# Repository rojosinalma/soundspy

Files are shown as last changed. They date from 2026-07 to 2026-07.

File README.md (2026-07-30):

<p align="center">
  soundspy logo
</p>

<h1 align="center">soundspy</h1>
<p align="center">Real-time multi-node sound monitoring system for ESP32</p>

---

ESP32 nodes with I2S microphones sample audio, perform 6-band frequency analysis, and publish to a web dashboard via MQTT. Designed to monitor when audio production might be disturbing neighbors through shared walls.

## Requirements

**Hardware (per node)**
- ESP32 development board
- ICS-43434 or INMP441 I2S MEMS microphone

**Software**
- Docker + Docker Compose
- Arduino CLI (for firmware builds) — or Arduino IDE

## Setup

**1. Configure environment**
```bash
cp .env.example .env
# Edit .env with your WiFi credentials and server IP
```

**2. Start services**
```bash
docker compose up -d
```
Dashboard: `http://<server-ip>:8091`

**3. Build and flash firmware**
```bash
./scripts/build_firmware.sh
# Initial flash via USB:
arduino-cli upload -p /dev/ttyUSB0 --fqbn esp32:esp32:esp32 \
  --input-file builds/soundspy_latest.bin
```
Subsequent updates can be done via OTA from the dashboard.

**Hardware wiring (I2S mic → ESP32)**

| Mic Pin | ESP32 GPIO |
|---|---|
| VDD | 3.3V |
| GND | GND |
| SD | GPIO32 |
| WS | GPIO25 |
| SCK | GPIO33 |
| L/R | GND |

## Development

**Project structure**
```
node_firmware/node_firmware.ino   — ESP32 firmware
dashboard/dashboard.py            — Flask + SocketIO backend
dashboard/templates/dashboard.html — Web UI
dashboard/threshold_monitor.py    — Alert service
scripts/build_firmware.sh         — Build script
scripts/deploy_ota.sh             — OTA deploy script
```

**OTA deploy to a node**
```bash
./scripts/deploy_ota.sh <chip_id>
# chip_id visible in dashboard or serial output on boot
```

**Useful commands**
```bash
docker logs -f soundspy_dashboard   # Dashboard logs
docker logs -f soundspy_monitor     # Alert service logs
```

## Documentation

Full documentation is available on the [project wiki](https://github.com/rojosinalma/soundspy/wiki):

- [Architecture](https://github.com/rojosinalma/soundspy/wiki/Architecture)
- [Hardware Wiring](https://github.com/rojosinalma/soundspy/wiki/Hardware-Wiring)
- [Firmware Setup](https://github.com/rojosinalma/soundspy/wiki/Firmware-Setup)
- [Dashboard](https://github.com/rojosinalma/soundspy/wiki/Dashboard)
- [Adding Nodes](https://github.com/rojosinalma/soundspy/wiki/Adding-Nodes)
- [Troubleshooting](https://github.com/rojosinalma/soundspy/wiki/Troubleshooting)

## Screenshot

<p align="center">
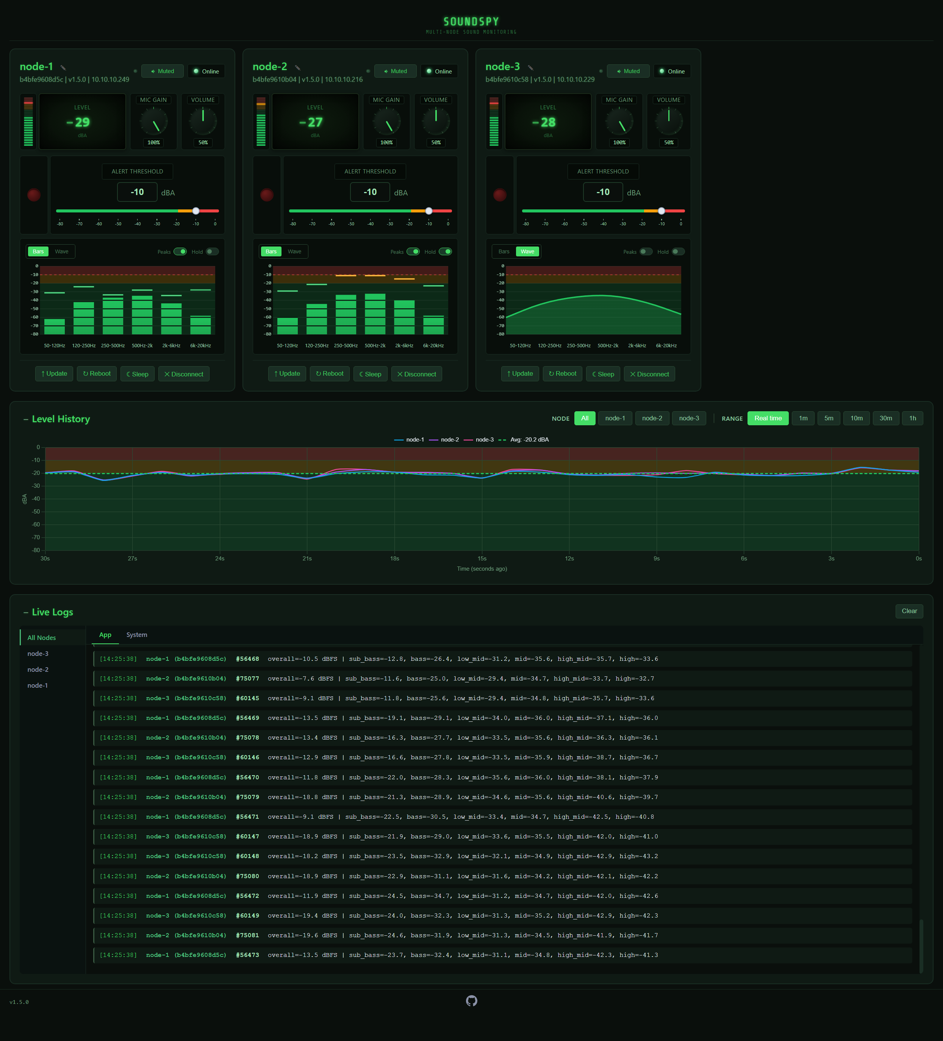
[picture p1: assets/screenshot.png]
soundspy dashboard
  
</p>

## License

[AGPL-3.0](LICENSE)

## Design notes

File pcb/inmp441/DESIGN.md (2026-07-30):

# INMP441 Mic Module

Circular breakout board with INMP441 MEMS I2S microphone.

## Module Specs

- **Dimensions:** 14mm diameter, 3mm height
- **Interface:** I2S
- **Header:** 2x3, 2.54mm column pitch, 7.62mm row separation
- **Drill:** 0.762mm, pad diameter 1.524mm
- **Sound port hole:** 3mm center drill

## Pin Layout

```
  GND   VDD   SD
   ●     ●     ●
  ( microphone  )
   ●     ●     ●
  LR    WS    SCK
```

| Pin | Signal | ESP32 GPIO |
|-----|---|---|
| VDD | 3.3V | 3.3V |
| GND | Ground | GND |
| SD  | I2S Data out | GPIO32 |
| WS  | I2S Word Select | GPIO25 |
| SCK | I2S Clock | GPIO33 |
| LR  | Channel select | GND (left channel) |

## Reference

- KiCad schematic symbol and footprint (legacy KiCad 4/5 format):
  https://github.com/barafael/inmp441-breakout-kicad

## Carrier Board Integration

The INMP441 module mounts on the `soundspy-node` carrier board (`pcb/soundspy-node.kicad_pcb`) via the 2x3 pin header. The carrier board has:

- A 3mm through-hole aligned with the mic's sound port
- 100nF decoupling cap (C1) on the 3V3 line near the connector
- Board outline: 30×68mm with USB-C notch at the bottom

## Notes

- LR pin must be tied to GND for left channel selection — connected to GND net on the carrier
- Route LR to GND during PCB layout in KiCad
- The carrier PCB is unrouted — open `soundspy-node.kicad_pcb` in KiCad and use the ratsnest to complete routing

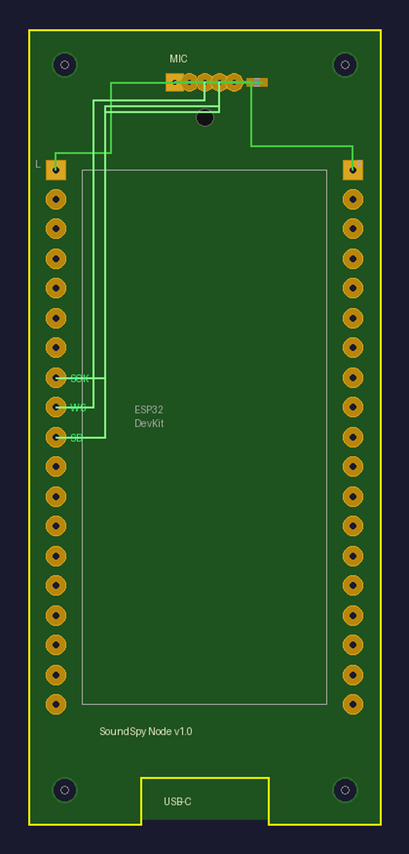
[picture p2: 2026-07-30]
pcb/inmp441/soundspy-node-preview.png

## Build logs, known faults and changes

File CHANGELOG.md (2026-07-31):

# Changelog

All notable changes to the soundspy project will be documented in this file.

The format is based on [Keep a Changelog](https://keepachangelog.com/en/1.0.0/),
and this project adheres to [Semantic Versioning](https://semver.org/spec/v2.0.0.html).

## Versioning Policy

- **MAJOR.MINOR.PATCH** (e.g., 0.8.3)
- **PATCH**: Bug fixes, optimization, logging changes (0.8.2 → 0.8.3)
- **MINOR**: New features, new capabilities (0.8.x → 0.9.0)
- **MAJOR**: Breaking changes, protocol changes, incompatible with dashboard (0.x.x → 1.0.0)

## [Unreleased]

## [1.6.0] - 2026-07-31

### Added
- EQ spectrum peak markers: always visible, fade after 2s by default
- Peaks toggle: hide/show peak markers per node
- Peak Hold toggle: keep markers indefinitely until exceeded again; enabling hold auto-enables peaks, disabling peaks auto-disables hold
- Per-node threshold persistence across page reloads (`data/node_thresholds.json`)
- System logs persist across reload: server keeps last 200, replays to new clients on connect
- Node name shown alongside chip ID in all log entries

### Changed
- Default mic gain raised to 100% (10x) for accurate level reporting
- Node chip ID now uses full 6-byte MAC (was lower 4 bytes) — fixes duplicate IDs on boards from same batch
- Threshold stored exactly as set by user — removed dBFS/dBA recalculation that caused drift on reload
- Offline status LED is now static red with glow (was dim green)
- Node history chart colors changed to blues/purples/pinks (avoids conflict with green/yellow/red zone colors)

### Fixed
- Node cards no longer flash: staleness check now uses browser clock (`Date.now()`) instead of server timestamp — eliminates clock-skew false positives
- Canvas no longer resets every frame: DPR dimensions rounded to integer, preventing always-true size mismatch
- DOM writes guarded against no-op updates; sensor data batched via `requestAnimationFrame`
- App log no longer causes layout thrashing at 50Hz — throttled to 1s renders

## [1.5.0] - 2026-07-31

### Changed
- Node chip ID now uses full 6-byte MAC (was lower 4 bytes) — fixes duplicate IDs on boards from same batch

### Fixed
- Release workflow no longer attempts to package PCB files (handled separately by `pcb-release.yml`)

## [1.4.9] - 2026-07-30

### Added
- Project wiki with full documentation (Architecture, Hardware Wiring, Firmware Setup, Dashboard, Adding Nodes, Troubleshooting)
- Wiki links in README
- AGPL-3.0 license
- VERSION file as single source of truth; bump_version.sh script to update all version strings at once
- GitHub Actions workflow to auto-tag and release when VERSION increases

## [1.4.8] - 2026-07-30

### Fixed
- Wave mode: fill and stroke gradients use hard stops at zone boundaries — no more yellow bleeding below threshold

## [1.4.7] - 2026-07-30

### Added
- Alert LED: red dome indicator next to threshold box, lights up instantly on threshold breach using raw level (not EMA-smoothed)

### Changed
- Audio indicator and online dot styled as LEDs: radial gradient highlight, glow when active, dark recessed dome when off
- Blink animation dimmer (35% opacity) for more visible pulse
- Status pill gap increased to 8px
- Node card no longer flashes border on alert — LED is the sole indicator
- Band frequency labels aligned to 6-column grid matching bar positions
- Spectrum canvas taller (160px), Y-axis narrower (30px)
- eq-container: dark bg + border matching control boxes

## [1.4.6] - 2026-07-30

### Added
- Dashboard version in footer (bottom-left, monospace, served from DASHBOARD_VERSION constant)
- watchdog hot-reload: template and Python changes now apply without container restart

### Changed
- Spectrum canvas renders at device pixel ratio — fixes blurry Y-axis text on HiDPI displays
- Spectrum canvas taller (160px), Y-axis narrower (30px) for more bar width
- Band frequency labels aligned to grid (6 equal columns) matching bar positions
- Y-axis numbers, band labels, slider marks/notches: #9ecfb0 (brighter green)
- Node info sub-text (chip ID, firmware, IP): #6b9e7a green
- Online/Sleeping/Offline pill text: #a3e6b8
- Button text: rgba(68, 221, 102, 0.9) phosphor green
- Bars/Wave toggle: single border wrapping both buttons
- eq-container: dark bg + border matching control boxes
- Filter labels: bold + #8ec9a0
- History chart axis labels: #6b9e7a

## [1.4.5] - 2026-07-30

### Changed
- Knob percentage values: dark display background, border, monospace font, larger size
- Knob labels (Mic Gain, Volume): dark display background with border
- Alert Threshold label: dark display background, generous padding (10px 20px)
- Button and selector text: brighter green (#8ec9a0, was #6b9e7a)
- Log Clear/Resume buttons: green border + text matching action button style
- Threshold input: centered with hidden spacer, unit label sits right beside it

## [1.4.4] - 2026-07-30

### Added
- Level History section is now collapsible (starts expanded, +/− toggle on left, hides filters when collapsed)

### Changed
- Level display: digits centered under label; minus sign absolutely positioned to the left without affecting layout
- Threshold input: centered with hidden spacer balancing the unit label on the right
- Button and selector text color shifted to #6b9e7a (muted green, was blue-grey)
- Offline/muted status dot and audio indicator: dark green (#2a4a34) instead of grey

## [1.4.3] - 2026-07-30

### Changed
- Buttons now have a subtle border (`#2a4a34`) at rest; border brightens to `#44dd66` on hover
- History selector buttons (node + time range) match button border style
- Filter labels ("Node", "Range") larger (`0.8em`) and green (`#6b9e7a`), spaced from first selector
- Node display names pre-populated on page load so selectors never flash the chip ID

## [1.4.2] - 2026-07-30

### Added
- Status pill for online/sleeping/offline — boxed background matching button style, not interactive
- Speaker SVG icon for mute/unmute button (fixed width so button doesn't resize on toggle)

### Changed
- Level meter bar moved to left of number display
- Level meter box: darker `#080e0a` background with green border
- Spectrum: 8px right padding to match top/bottom margins
- Control boxes (knobs, threshold): darker background + green border for instrument panel feel
- Alert threshold: top-padding and auto-height so markers stay inside box
- Threshold input, knob percentage, log seq number: `#a3e6b8` mint color
- Control box labels: `#6b9e7a` muted green (was blue-grey `#8b92a8`)
- dBA/dBFS toggle label: `#6b9e7a`, brightens to `#44dd66` on hover
- Level number: fixed `3ch` min-width so minus sign doesn't shift display off-center
- Update button ↑ icon vertically aligned with text
- Live logs toggle: `+`/`−` on left instead of arrow
- Level meter bar zone backgrounds inset to match segment width (fixes wider-at-top illusion)

### Fixed
- Alert threshold defaults to -20 dBA; calibrates to dBFS on first band data arrival
- Toggling dBFS↔dBA no longer drifts the threshold value
- PCB file: removed invalid `;;` comments that prevented KiCad import

## [1.4.1] - 2026-07-30

### Added
- dBA default: dashboard loads in dBA mode; toggle label, threshold unit, chart Y-axis, and avg line label all switch together
- Threshold stored internally as dBFS; displayed and compared in active unit using cached A-weighting offset per node
- A-weighting offset cached on first band data arrival (not recomputed per frame) — fixes moving threshold line
- Level meter bar now follows raw unsmoothed signal; number display remains EMA-smoothed

### Fixed
- Threshold line in spectrum no longer drifts when bands fluctuate
- All zone backgrounds, bar colors, and alert comparisons use display-unit threshold consistently

## [1.4.0] - 2026-07-30

### Added
- Sleep/wake: nodes now enter soft sleep (I2S stopped, WiFi+MQTT alive) instead of deep sleep — can be woken remotely from dashboard
- Heartbeat: nodes publish to `soundspy/<chip_id>/heartbeat` every 30s (uptime, sleep state, free heap)
- Backend tracks sleep state and uses heartbeat for online detection (sleeping node goes offline after 60s of missed heartbeats)
- dBFS/dBA toggle on level display — click the unit label to switch; affects level meter, spectrum bars, and history chart
- Firmware version updates live via socket without page reload

### Fixed
- History chart averaging now done in linear power domain (was averaging dBFS directly — compresses dynamic range)
- Offline/sleeping nodes drop level and spectrum to floor immediately
- Sleeping nodes show "Sleeping" status (not "Offline") with wake button
- Sleep state persists across page reloads (tracked server-side)
- Chart grid lines brighter (#2a4a34)
- Filter separator lines brighter (#3a5a42)
- "Real time" selector label (no hyphen)
- Average line legend toggle no longer resets on each chart update (stable key fix)
- Threshold control spacing increased between input box and slider

## [1.3.1] - 2026-07-30

### Fixed
- Duplicate chip IDs across boards: now uses lower 4 bytes of EfuseMAC (8-char hex) instead of middle 3 bytes which collided on chips from same batch

### Changed
- Dashboard color palette shifted from blue/purple to green (hardware EQ aesthetic)
- Header uses Share Tech Mono font with phosphor green glow
- Node display names update live on existing cards (not only on card creation)
- Node rename uses inline contenteditable (no browser prompt)
- Edit button (✎) next to node name, audio indicator moved next to mute button
- Mute/unmute button uses ◁ icon, online dot has green glow

## [1.3.0] - 2026-07-30

### Changed
- **BREAKING**: Node ID no longer configured at build time — derived from ESP32 chip ID at runtime (lower 3 bytes of EfuseMAC as 6-char hex)
- Firmware binary is now generic: compile once, flash to any ESP32
- MQTT topics use chip ID: `soundspy/<chip_id>/data` (e.g. `soundspy/a1b2c3/data`)
- Build script no longer takes NODE_ID argument, produces `soundspy_v<version>.bin`
- Deploy script takes chip_id (visible in dashboard) as argument
- NODE_ID removed from `.env`

### Added
- Node name persistence: `data/node_names.json` maps chip IDs to display names
- Auto-naming: new nodes assigned "node-1", "node-2", etc. on first connect
- Rename nodes via double-click in dashboard UI or `POST /api/node/rename`
- Display names shown in node cards, history chart selector, logs
- `data/` volume mounted into dashboard container for state persistence

## [1.2.1] - 2026-07-30

### Added
- Per-node threshold tracking with history chart node selector
- Vertical level meter bar (segmented, with peak hold and zone colors)
- Threshold slider: tick marks every 10dB, snap-to-mark, dynamic zone indicators (▲)
- Slider double-click resets to -20, step=0.5 dBFS
- Overall level display restyled as CRT oscilloscope (phosphor green, vignette)
- Remote logging over MQTT (`soundspy/<node>/log` and `/boot` topics)
- OTA rollback: `esp_ota_mark_app_valid_cancel_rollback()` gates on MQTT connectivity
- Boot report published to MQTT with partition, reset reason, free heap, IP
- Two-stage boot order: WiFi → MQTT → OTA confirm → I2S → WebSocket
- Live logs panel in dashboard: per-node sidebar + app/system tab split
- Deep sleep command (`{"sleep": true}`) for safe power-off
- I2S watchdog stays alive in degraded mode after 3 failed reinits (keeps MQTT)

### Changed
- MQTT buffer increased to 512 bytes
- Boot messages flush with `mqtt.loop()` after publish

## [1.1.0] - 2026-07-30

### Changed
- All firmware config (WiFi, MQTT, WS, NODE_ID) moved to PLACEHOLDER_* tokens
- Version is the only hardcoded value in firmware source
- Build script extracts version from .ino (not .env)
- Build generates `node_firmware.rendered.ino` for Arduino IDE manual flashing

### Removed
- FIRMWARE_VERSION from `.env` (now source-of-truth is the .ino)

## [1.0.0] - 2026-07-30

### Added
- I2S watchdog: auto-reinitializes bus after 5 consecutive -180 dBFS readings, reboots if reinit fails
- Custom confirm modal (replaces browser confirm() dialogs)

### Changed
- Firmware consolidated to single file: `node_firmware/node_firmware.ino`
- Credentials removed from source — all config injected from `.env` at build time
- Threshold input spinner arrows removed (use slider or type directly)
- Build script sed patterns simplified for robustness

### Removed
- Legacy firmware files (`node.ino`, `node_multiband.ino`)
- Hardcoded WiFi/MQTT credentials from firmware source
- Old firmware files purged from git history

## [0.9.3] - 2026-07-30

### Added
- Reboot command via MQTT control channel (`{"reboot": true}`)
- History chart colored zone backgrounds (green/yellow/red)
- Average level line (flat dotted) on history chart with zone-colored styling
- Multi-node color palette for history chart (supports unlimited nodes)
- Knob snapping at 10% increments with 11 notch marks
- Double-click knobs to reset to defaults
- EMA smoothing on overall level display
- Live log scroll pause with Resume button
- GitHub footer link
- Window resize handler for log expansion

### Changed
- Frequency bands realigned for ICS-43434 mic (50 Hz–20 kHz)
- New biquad bandpass coefficients for all 6 bands
- Zone thresholds: Green < -20, Yellow -20 to -10, Red > -10 dBFS
- Default alert threshold: -20 dBFS
- Mic gain range reduced to 0–10x (was 0–20x), default 4x (40%)
- Knob sweep expanded to 300° (was 270°)
- History chart: fixed Y-axis (-80 to 0), normalized X-axis (full width)
- History downsampled to 1 point/sec (was raw ~20Hz)
- Default time range: 1 minute (was 5 minutes)
- Overall level displays as integer (was 1 decimal)
- Wave visualization uses zone colors (was multicolor gradient)
- Threshold slider gradient matches zone boundaries
- Header restyled with gradient title
- Live log renamed, collapsible with proper sizing
- Dashboard container uses volume mounts for live reload
- Flask debug mode with auto-reloader

### Removed
- Latency tracking from log entries and backend

### Fixed
- History chart line not spanning full width
- Knob indicator not aligning with notch marks
- dBFS values below -80 showing as -180 (now clamped)

## [0.9.0] - 2026-07-30

### Changed
- Frequency bands realigned for INMP441 mic (60 Hz–15 kHz)
- Mic gain default reduced to 2x, max to 10x

## [0.8.4] - 2026-07-29

### Added
- `deploy_ota.sh` script for automated OTA deployment
- `init_arduino.sh` script for toolchain setup
- Automated OTA workflow (build → upload → trigger)

## [0.8.3] - 2026-07-29

### Added
- `.env` file support for centralized configuration management
- `.env.example` template file for easy setup
- `build_firmware.sh` script to compile firmware with injected .env values
- Environment variable support in docker-compose.yml
- Firmware output directory (`firmware/`)

### Changed
- Moved sensitive configuration (WiFi, MQTT) to `.env` file
- Updated docker-compose.yml to use environment variables
- Updated .gitignore to exclude .env and .bin files
- Firmware config values now injected at build time from .env

## [0.8.2] - 2026-07-29

### Fixed
- Removed LED_BUILTIN reference causing compilation errors on some ESP32 boards

## [0.8.1] - 2026-07-29

### Changed
- Reduced serial logging spam - only important events logged
- Added `[IMPORTANT]` tag to critical log messages
- Removed 50Hz sensor data from serial output
- Added startup banner with version and node ID
- OTA progress now logged every 10% instead of continuous

### Added
- Cleaner serial monitor output for debugging

## [0.8.0] - 2026-07-29

### Added
- OTA (Over-The-Air) firmware update support via HTTP
- Dashboard firmware upload interface with modal dialog
- Firmware version reporting via MQTT
- Version display on dashboard (per node)
- `/api/ota/upload` endpoint for firmware uploads
- `/api/ota/trigger` endpoint to initiate OTA updates
- `/firmware/<filename>` endpoint to serve firmware files to ESP32

### Changed
- Bumped to MINOR version for new OTA feature
- Updated dashboard UI with "📡 Update" button per node

## [0.7.6] - 2026-07-29

### Added
- Include firmware version in every data message (not just on connect)

## [0.7.5] - 2026-07-29

### Added
- Firmware version reporting via MQTT on connection

## [0.7.0] - 2026-07-29

### Fixed
- **CRITICAL**: Apply mic gain early in signal chain
  - Gain now affects both frequency analysis AND audio streaming
  - Previously gain only affected audio, not frequency readings
  - Setting gain to 0% now stops all processing correctly

### Changed
- Moved gain application before frequency band filtering

## [0.6.0] - 2026-07-29

### Added
- Real-time audio streaming via WebSocket
- Raw WebSocket endpoint (`/ws/audio`) for ESP32 audio streaming
- Audio playback controls on dashboard (mute/unmute per node)
- Browser volume control (separate from mic gain)
- Web Audio API integration with scheduled buffer playback

## [0.5.0] - 2026-07-29

### Added
- Multi-band frequency analysis (6 bands)
- Bands: sub-bass (20-60Hz), bass (60-250Hz), low-mid (250-500Hz), mid (500-2kHz), high-mid (2k-4kHz), high (4k-8kHz)
- Cascaded Butterworth biquad bandpass filters
- Real-time frequency visualization on dashboard
- EQ-style spectrum display (bars and wave modes)
- Professional audio meter styling with color-coded levels
- Peak hold markers with fade effect

### Changed
- Increased publish rate to 50Hz for responsive readings
- Expanded MQTT payload to include all frequency bands

## [0.4.0] - 2026-07-29

### Added
- Web dashboard with Flask + SocketIO
- Real-time WebSocket updates (replaced SSE)
- Remote mic gain control via MQTT
- Rotary knob UI for gain adjustment
- Historical chart with Chart.js (5-minute rolling window)
- Live data log with sequence numbers and latency display

### Changed
- Switched from Server-Sent Events to WebSocket for lower latency
- Improved dashboard rendering performance

## [0.3.0] - 2026-07-29

### Added
- Docker-based backend services
- Mosquitto MQTT broker
- ntfy notification service
- Threshold monitoring service
- Per-node cooldown for alerts

## [0.2.0] - 2026-07-29

### Added
- Basic ESP32 firmware with I2S audio sampling
- MQTT publishing of dBFS levels
- Overall level and bass-band measurements

## [0.1.0] - 2026-07-29

### Added
- Initial project structure
- Basic README documentation
- Hardware wiring documentation

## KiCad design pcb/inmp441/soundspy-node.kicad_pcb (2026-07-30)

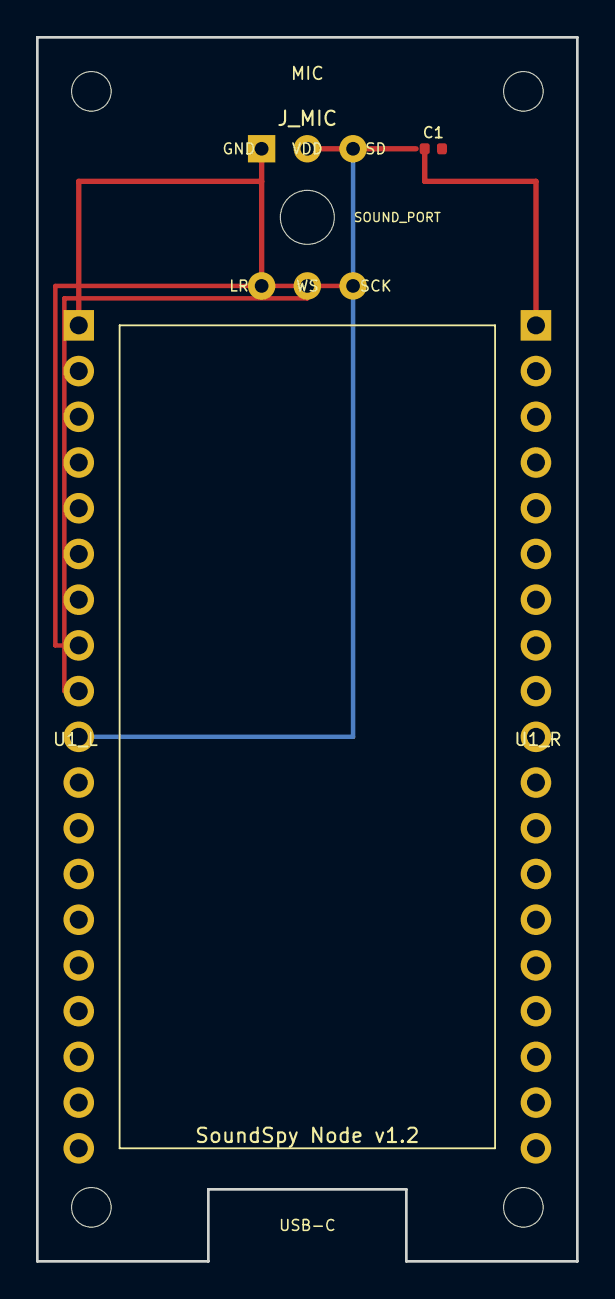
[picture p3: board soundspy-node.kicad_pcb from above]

Board: 2 copper layers, 30.0 x 68.0 mm, 5 parts (0 on the bottom side), 5 nets.

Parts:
C1: 100nF; C_0402_1005Metric
J_MIC: INMP441; PinHeader_2x03_P2.54mm_Vertical
SOUND_PORT: MountingHole_3.2mm
U1_L: ESP32_L; PinHeader_1x19_P2.54mm_Vertical
U1_R: ESP32_R; PinHeader_1x19_P2.54mm_Vertical

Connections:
3V3: C1.1, J_MIC.2, U1_R.1
GND: C1.2, J_MIC.1, U1_L.1
I2S_SCK: J_MIC.6, U1_L.8
I2S_SD: J_MIC.3, U1_L.10
I2S_WS: J_MIC.5, U1_L.9

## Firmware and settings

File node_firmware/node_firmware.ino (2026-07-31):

// soundspy node firmware — ESP32 + ICS-43434 I2S MEMS mic

#include <WiFi.h>
#include <PubSubClient.h>
#include <WebSocketsClient.h>
#include <HTTPUpdate.h>
#include <esp_ota_ops.h>
#include <driver/i2s.h>
#include <math.h>
#include <base64.h>
#include <ArduinoJson.h>
#include <esp_system.h>
#include <Preferences.h>

const char* FIRMWARE_VERSION = "1.7.7";
const char* FIRMWARE_BUILD   = __DATE__ " " __TIME__;  // e.g. "Jul 31 2026 20:45:12"

// --- NVS credentials (written by recovery portal or build_firmware.sh on first flash) ---
static char WIFI_SSID_BUF[64];
static char WIFI_PASS_BUF[64];
static char MQTT_HOST_BUF[64];
static int  MQTT_PORT_VAL = 1883;
static char WS_HOST_BUF[64];
static int  WS_PORT_VAL  = 8091;

const char* WIFI_SSID  = WIFI_SSID_BUF;
const char* WIFI_PASS  = WIFI_PASS_BUF;
const char* MQTT_HOST  = MQTT_HOST_BUF;
const char* WS_HOST    = WS_HOST_BUF;

void loadCredentials() {
  Preferences prefs;
  prefs.begin("soundspy", true);
  strlcpy(WIFI_SSID_BUF, prefs.getString("wifi_ssid", "PLACEHOLDER_WIFI_SSID").c_str(), sizeof(WIFI_SSID_BUF));
  strlcpy(WIFI_PASS_BUF, prefs.getString("wifi_pass", "PLACEHOLDER_WIFI_PASS").c_str(), sizeof(WIFI_PASS_BUF));
  strlcpy(MQTT_HOST_BUF, prefs.getString("mqtt_host", "PLACEHOLDER_MQTT_HOST").c_str(), sizeof(MQTT_HOST_BUF));
  MQTT_PORT_VAL = prefs.getInt("mqtt_port", PLACEHOLDER_MQTT_PORT);
  strlcpy(WS_HOST_BUF,   prefs.getString("ws_host",   "PLACEHOLDER_WS_HOST").c_str(), sizeof(WS_HOST_BUF));
  WS_PORT_VAL = prefs.getInt("ws_port", PLACEHOLDER_WS_PORT);
  prefs.end();
}

// --- Crash counter in NVS (survives all resets including hard reboot + power loss) ---
#define CRASH_BOOT_LIMIT 3

uint32_t crashBootCount = 0;

void crashCounterLoad() {
  Preferences prefs;
  prefs.begin("soundspy_boot", false);
  crashBootCount = prefs.getUInt("crash_count", 0);
  prefs.end();
}

void crashCounterIncrement() {
  Preferences prefs;
  prefs.begin("soundspy_boot", false);
  crashBootCount++;
  prefs.putUInt("crash_count", crashBootCount);
  prefs.end();
}

void crashCounterReset() {
  crashBootCount = 0;
  Preferences prefs;
  prefs.begin("soundspy_boot", false);
  prefs.putUInt("crash_count", 0);
  prefs.end();
}

void bootIntoRecovery() {
  Serial.println("[IMPORTANT] Crash limit reached — booting into recovery");
  const esp_partition_t* factory = esp_partition_find_first(
    ESP_PARTITION_TYPE_APP, ESP_PARTITION_SUBTYPE_APP_FACTORY, NULL);
  if (factory) {
    esp_ota_set_boot_partition(factory);
    delay(200);
    esp_restart();
  }
  // If no factory partition, just hang — USB flash required
  Serial.println("[IMPORTANT] No factory partition found — connect via USB");
  while (true) delay(1000);
}

// --- Boot attempt tracking via RTC memory (survives reboot, not power loss) ---
#define BOOT_MAGIC 0xB007CA11

#define BOOT_STAGE_INIT    0
#define BOOT_STAGE_WIFI    1
#define BOOT_STAGE_MQTT    2
#define BOOT_STAGE_OTA_OK  3
#define BOOT_STAGE_I2S     4
#define BOOT_STAGE_VALID   0xFF  // fully validated

struct BootRecord {
  uint32_t magic;
  char firmware[16];
  uint8_t stage;
  uint8_t attempt;
};

RTC_DATA_ATTR BootRecord rtcBoot;     // current boot attempt
RTC_DATA_ATTR BootRecord rtcPrevBoot; // copy of last attempt before we overwrite it
RTC_DATA_ATTR bool rtcPrevValid;      // true if rtcPrevBoot has data worth reporting

void bootStage(uint8_t stage) {
  rtcBoot.stage = stage;
}

// Node ID derived from chip's unique ID (lower 4 bytes of MAC)
char NODE_ID[13];

// I2S pins
#define I2S_WS   25
#define I2S_SD   32
#define I2S_SCK  33
#define I2S_PORT I2S_NUM_0

// Audio config
#define SAMPLE_RATE     44100
#define SAMPLES_PER_READ 1024
#define PUBLISH_INTERVAL_MS 20  // 50Hz update rate

// Audio streaming config
#define STREAM_CHUNK_SIZE 4410    // 100ms chunks at 44.1kHz

int32_t i2s_read_buf[SAMPLES_PER_READ];
int16_t audioStreamBuffer[STREAM_CHUNK_SIZE];
int audioStreamIndex = 0;

// Remote-controllable gain
float audioGain = 10.0f;  // Default gain (20dB)

// Sleep mode — keeps WiFi+MQTT alive but stops I2S processing
bool sleeping = false;

// Heartbeat interval (ms)
#define HEARTBEAT_INTERVAL_MS 10000
unsigned long lastHeartbeat = 0;

WiFiClient espClient;
PubSubClient mqtt(espClient);
WebSocketsClient webSocket;

void remoteLog(const char* level, const char* msg) {
  Serial.printf("[%s] %s\n", level, msg);
  if (mqtt.connected()) {
    char payload[384];
    snprintf(payload, sizeof(payload),
      "{\"node\":\"%s\",\"level\":\"%s\",\"msg\":\"%s\",\"uptime_ms\":%lu,\"firmware\":\"%s\"}",
      NODE_ID, level, msg, millis(), FIRMWARE_VERSION);
    String topic = String("soundspy/") + NODE_ID + "/log";
    mqtt.publish(topic.c_str(), payload);
  }
}

void publishBootReport() {
  const esp_partition_t* running = esp_ota_get_running_partition();
  char payload[512];
  int len = snprintf(payload, sizeof(payload),
    "{\"node\":\"%s\",\"firmware\":\"%s\",\"reset_reason\":%d,\"partition\":\"%s\",\"free_heap\":%u,\"ip\":\"%s\"",
    NODE_ID, FIRMWARE_VERSION, (int)esp_reset_reason(),
    running ? running->label : "unknown",
    ESP.getFreeHeap(),
    WiFi.localIP().toString().c_str());

  if (rtcPrevValid && rtcPrevBoot.magic == BOOT_MAGIC && rtcPrevBoot.stage != BOOT_STAGE_VALID) {
    const char* stageNames[] = {"init","wifi","mqtt","ota_ok","i2s"};
    const char* stageName = (rtcPrevBoot.stage < 5) ? stageNames[rtcPrevBoot.stage] : "unknown";
    len += snprintf(payload + len, sizeof(payload) - len,
      ",\"prev_failed_boot\":{\"firmware\":\"%s\",\"stage\":\"%s\",\"stage_id\":%d}",
      rtcPrevBoot.firmware, stageName, rtcPrevBoot.stage);
    rtcPrevValid = false;  // clear after reporting
  }

  snprintf(payload + len, sizeof(payload) - len, "}");
  String topic = String("soundspy/") + NODE_ID + "/boot";
  mqtt.publish(topic.c_str(), payload);
}

// 2nd-order biquad filter
struct Biquad {
  float b0, b1, b2, a1, a2;
  float z1 = 0, z2 = 0;
  float process(float in) {
    float out = b0 * in + z1;
    z1 = b1 * in + z2 - a1 * out;
    z2 = b2 * in - a2 * out;
    return out;
  }
};

struct FreqBand {
  const char* name;
  Biquad bp1, bp2;
  double sumSquares = 0;
};

FreqBand bands[] = {
  {"sub_bass"},  // 50-120 Hz
  {"bass"},      // 120-250 Hz
  {"low_mid"},   // 250-500 Hz
  {"mid"},       // 500-2000 Hz
  {"high_mid"},  // 2000-6000 Hz
  {"high"}       // 6000-20000 Hz
};

const int NUM_BANDS = sizeof(bands) / sizeof(bands[0]);

double sumSquaresOverall = 0;
uint32_t sampleCount = 0;
unsigned long lastPublish = 0;
uint32_t messageSeq = 0;

// I2S watchdog — detect bus lockup (sustained -180 dBFS)
#define I2S_WATCHDOG_THRESHOLD 150  // ~3 seconds at 50Hz before reinit
#define I2S_WATCHDOG_DBFS_FLOOR -170.0f
#define I2S_STARTUP_GRACE_MS 5000   // ignore dead reads for 5s after boot
int i2sLockupCount = 0;
unsigned long bootTime = 0;

int i2sReinitCount = 0;

void reinitI2S() {
  remoteLog("warn", "I2S watchdog: reinitializing bus");
  i2s_driver_uninstall(I2S_PORT);
  delay(200);
  setupI2S();
  size_t discard;
  for (int i = 0; i < 4; i++) {
    i2s_read(I2S_PORT, i2s_read_buf, sizeof(i2s_read_buf), &discard, 100);
  }
  i2sReinitCount++;
}

void configureBands() {
  // Bands aligned to ICS-43434 usable range (50 Hz - 20 kHz)
  bands[0].bp1 = {0.004962f, 0.0f, -0.004962f, -1.9900f, 0.9901f};
  bands[0].bp2 = {0.004962f, 0.0f, -0.004962f, -1.9900f, 0.9901f};
  bands[1].bp1 = {0.009175f, 0.0f, -0.009175f, -1.9810f, 0.9816f};
  bands[1].bp2 = {0.009175f, 0.0f, -0.009175f, -1.9810f, 0.9816f};
  bands[2].bp1 = {0.017491f, 0.0f, -0.017491f, -1.9625f, 0.9650f};
  bands[2].bp2 = {0.017491f, 0.0f, -0.017491f, -1.9625f, 0.9650f};
  bands[3].bp1 = {0.096246f, 0.0f, -0.096246f, -1.7892f, 0.8075f};
  bands[3].bp2 = {0.096246f, 0.0f, -0.096246f, -1.7892f, 0.8075f};
  bands[4].bp1 = {0.214777f, 0.0f, -0.214777f, -1.3830f, 0.5704f};
  bands[4].bp2 = {0.214777f, 0.0f, -0.214777f, -1.3830f, 0.5704f};
  bands[5].bp1 = {0.389863f, 0.0f, -0.389863f, -0.0123f, 0.2203f};
  bands[5].bp2 = {0.389863f, 0.0f, -0.389863f, -0.0123f, 0.2203f};
}

void setupI2S() {
  i2s_config_t i2s_config = {
    .mode = (i2s_mode_t)(I2S_MODE_MASTER | I2S_MODE_RX),
    .sample_rate = SAMPLE_RATE,
    .bits_per_sample = I2S_BITS_PER_SAMPLE_32BIT,
    .channel_format = I2S_CHANNEL_FMT_ONLY_LEFT,
    .communication_format = I2S_COMM_FORMAT_STAND_I2S,
    .intr_alloc_flags = ESP_INTR_FLAG_LEVEL1,
    .dma_buf_count = 8,
    .dma_buf_len = SAMPLES_PER_READ,
    .use_apll = false,
    .tx_desc_auto_clear = false,
    .fixed_mclk = 0
  };

  i2s_pin_config_t pin_config = {
    .bck_io_num = I2S_SCK,
    .ws_io_num = I2S_WS,
    .data_out_num = I2S_PIN_NO_CHANGE,
    .data_in_num = I2S_SD
  };

  i2s_driver_install(I2S_PORT, &i2s_config, 0, NULL);
  i2s_set_pin(I2S_PORT, &pin_config);
}

void connectWiFi() {
  WiFi.begin(WIFI_SSID, WIFI_PASS);
  Serial.print("[IMPORTANT] Connecting to WiFi");
  while (WiFi.status() != WL_CONNECTED) {
    delay(500);
    Serial.print(".");
  }
  Serial.println(" connected");
}

void performOTA(const char* firmwareUrl) {
  Serial.println("[IMPORTANT] Starting OTA update...");
  Serial.print("[IMPORTANT] Firmware URL: ");
  Serial.println(firmwareUrl);

  WiFiClient client;
  // Don't use LED_BUILTIN as it may not be defined on all boards
  // httpUpdate.setLedPin(LED_BUILTIN, LOW);

  httpUpdate.onStart([]() {
    Serial.println("[IMPORTANT] OTA started - downloading firmware");
  });

  httpUpdate.onEnd([]() {
    Serial.println("[IMPORTANT] OTA finished successfully");
  });

  httpUpdate.onProgress([](int current, int total) {
    static int lastPercent = -1;
    int percent = (current * 100) / total;
    // Only log every 10%
    if (percent >= lastPercent + 10) {
      Serial.printf("[IMPORTANT] OTA Progress: %d%%\n", percent);
      lastPercent = percent;
    }
  });

  httpUpdate.onError([](int error) {
    Serial.printf("[IMPORTANT] OTA Error[%d]: ", error);
    Serial.println(httpUpdate.getLastErrorString());
  });

  t_httpUpdate_return ret = httpUpdate.update(client, firmwareUrl);

  switch (ret) {
    case HTTP_UPDATE_FAILED:
      Serial.printf("[IMPORTANT] OTA failed: %s\n", httpUpdate.getLastErrorString().c_str());
      break;
    case HTTP_UPDATE_NO_UPDATES:
      Serial.println("[IMPORTANT] No updates available");
      break;
    case HTTP_UPDATE_OK:
      Serial.println("[IMPORTANT] Update successful, rebooting...");
      if (mqtt.connected()) {
        char otaPayload[192];
        snprintf(otaPayload, sizeof(otaPayload),
          "{\"node\":\"%s\",\"status\":\"success\",\"url\":\"%s\"}", NODE_ID, firmwareUrl);
        String otaTopic = String("soundspy/") + NODE_ID + "/ota";
        mqtt.publish(otaTopic.c_str(), otaPayload);
        mqtt.loop();
        delay(300);
      }
      esp_restart();
      break;
  }
}

void mqttCallback(char* topic, byte* payload, unsigned int length) {
  // Parse control messages
  StaticJsonDocument<256> doc;
  DeserializationError error = deserializeJson(doc, payload, length);

  if (error) {
    Serial.print("JSON parse error: ");
    Serial.println(error.c_str());
    return;
  }

  // Handle OTA update
  if (doc.containsKey("ota_url")) {
    const char* firmwareUrl = doc["ota_url"];
    Serial.println("[IMPORTANT] OTA update requested");
    performOTA(firmwareUrl);
    return;  // Function will reboot after update
  }

  // Handle reboot command
  if (doc.containsKey("reboot") && doc["reboot"] == true) {
    remoteLog("info", "Reboot requested");
    delay(200);
    esp_restart();
  }

  // Handle sleep/wake — stops I2S processing but keeps WiFi+MQTT alive
  if (doc.containsKey("sleep") && doc["sleep"] == true && !sleeping) {
    sleeping = true;
    i2s_driver_uninstall(I2S_PORT);
    remoteLog("info", "Sleeping (I2S stopped, MQTT alive)");
    mqtt.loop();
  }
  if (doc.containsKey("wake") && doc["wake"] == true && sleeping) {
    sleeping = false;
    setupI2S();
    size_t discard;
    for (int i = 0; i < 4; i++) {
      i2s_read(I2S_PORT, i2s_read_buf, sizeof(i2s_read_buf), &discard, 100);
    }
    bootTime = millis();
    remoteLog("info", "Woke up (I2S restarted)");
    mqtt.loop();
  }

  // Handle gain control
  if (doc.containsKey("gain")) {
    float newGain = doc["gain"];
    if (newGain >= 0.0f && newGain <= 10.0f) {  // Safety limits for INMP441
      audioGain = newGain;
      Serial.print("[IMPORTANT] Gain updated to: ");
      Serial.println(audioGain);
    }
  }
}

void connectMQTT() {
  mqtt.setBufferSize(512);
  mqtt.setServer(MQTT_HOST, MQTT_PORT_VAL);
  mqtt.setCallback(mqttCallback);

  while (!mqtt.connected()) {
    Serial.print("[IMPORTANT] Connecting to MQTT...");
    String clientId = String("esp32-") + NODE_ID;
    if (mqtt.connect(clientId.c_str())) {
      Serial.println(" connected");

      // Subscribe to control topic
      String controlTopic = String("soundspy/") + NODE_ID + "/control";
      mqtt.subscribe(controlTopic.c_str());
      Serial.print("[IMPORTANT] Subscribed to: ");
      Serial.println(controlTopic);

      // Publish version info on connect
      String versionTopic = String("soundspy/") + NODE_ID + "/version";
      String versionPayload = String("{\"node\":\"") + NODE_ID + "\",\"firmware\":\"" + FIRMWARE_VERSION + "\",\"build\":\"" + FIRMWARE_BUILD + "\"}";
      mqtt.publish(versionTopic.c_str(), versionPayload.c_str());
      Serial.print("[IMPORTANT] Published firmware version: ");
      Serial.println(FIRMWARE_VERSION);
    } else {
      Serial.print("[IMPORTANT] failed, rc=");
      Serial.print(mqtt.state());
      Serial.println(" retrying in 2s");
      delay(2000);
    }
  }
}

void webSocketEvent(WStype_t type, uint8_t * payload, size_t length) {
  switch(type) {
    case WStype_DISCONNECTED:
      Serial.println("[IMPORTANT] WebSocket disconnected");
      break;
    case WStype_CONNECTED:
      Serial.println("[IMPORTANT] WebSocket connected");
      break;
  }
}

void connectWebSocket() {
  webSocket.begin(WS_HOST, WS_PORT_VAL, "/ws/audio");
  webSocket.onEvent(webSocketEvent);
  webSocket.setReconnectInterval(5000);
}

void sendAudioChunk() {
  // Base64 encode the audio buffer
  String encoded = base64::encode((uint8_t*)audioStreamBuffer, audioStreamIndex * 2);

  // Send via WebSocket as JSON
  String payload = "{\"node_id\":\"" + String(NODE_ID) + "\",\"audio\":\"" + encoded + "\"}";
  webSocket.sendTXT(payload);

  audioStreamIndex = 0;
}

void setup() {
  Serial.begin(115200);

  // Derive node ID from chip's full 6-byte fuse MAC (deterministic, no config needed)
  uint64_t mac = ESP.getEfuseMac();
  snprintf(NODE_ID, sizeof(NODE_ID), "%02x%02x%02x%02x%02x%02x",
    (uint8_t)(mac), (uint8_t)(mac >> 8), (uint8_t)(mac >> 16),
    (uint8_t)(mac >> 24), (uint8_t)(mac >> 32), (uint8_t)(mac >> 40));


  // Crash counter — if crashed too many times, enter recovery
  crashCounterLoad();
  crashCounterIncrement();
  Serial.printf("[IMPORTANT] Boot attempt %u/%u\n", crashBootCount, CRASH_BOOT_LIMIT);
  if (crashBootCount > CRASH_BOOT_LIMIT) {
    crashCounterReset();
    bootIntoRecovery();
  }

  // Load credentials from NVS
  loadCredentials();

  Serial.println("\n\n[IMPORTANT] ========================================");
  Serial.print("[IMPORTANT] soundspy node starting - Firmware v");
  Serial.println(FIRMWARE_VERSION);
  Serial.print("[IMPORTANT] Node ID: ");
  Serial.println(NODE_ID);
  Serial.println("[IMPORTANT] ========================================\n");


  // Save previous boot record before overwriting
  if (rtcBoot.magic == BOOT_MAGIC && rtcBoot.stage != BOOT_STAGE_VALID) {
    rtcPrevBoot = rtcBoot;
    rtcPrevValid = true;
  } else {
    rtcPrevValid = false;
  }

  // Initialise new boot record
  rtcBoot.magic = BOOT_MAGIC;
  strncpy(rtcBoot.firmware, FIRMWARE_VERSION, sizeof(rtcBoot.firmware) - 1);
  rtcBoot.firmware[sizeof(rtcBoot.firmware) - 1] = '\0';
  rtcBoot.stage = BOOT_STAGE_INIT;
  rtcBoot.attempt = (rtcPrevValid ? rtcPrevBoot.attempt + 1 : 0);

  connectWiFi();
  bootStage(BOOT_STAGE_WIFI);

  connectMQTT();
  bootStage(BOOT_STAGE_MQTT);

  // Confirm OTA partition is valid — if this never runs, bootloader rolls back
  esp_ota_mark_app_valid_cancel_rollback();
  // Don't reset crash counter yet — wait for stability window in loop()
  bootStage(BOOT_STAGE_OTA_OK);

  publishBootReport();
  remoteLog("boot", "Stage 1 OK: WiFi + MQTT connected");
  mqtt.loop();

  configureBands();
  setupI2S();
  bootStage(BOOT_STAGE_I2S);
  connectWebSocket();
  lastPublish = millis();
  bootTime = millis();

  // All stages passed — mark as fully valid
  bootStage(BOOT_STAGE_VALID);

  remoteLog("boot", "Stage 2 OK: I2S + WebSocket initialized");
  mqtt.loop();
}

void sendHeartbeat() {
  if (millis() - lastHeartbeat < HEARTBEAT_INTERVAL_MS) return;
  lastHeartbeat = millis();
  unsigned long uptime = millis() / 1000;
  char msg[128];
  snprintf(msg, sizeof(msg), "node=%s fw=%s uptime=%lus heap=%u mqtt=%s",
    NODE_ID, FIRMWARE_VERSION, uptime, ESP.getFreeHeap(),
    mqtt.connected() ? "ok" : "disconnected");
  remoteLog("heartbeat", msg);
  char payload[128];
  snprintf(payload, sizeof(payload),
    "{\"node\":\"%s\",\"uptime_ms\":%lu,\"sleeping\":%s,\"free_heap\":%u}",
    NODE_ID, millis(), sleeping ? "true" : "false", ESP.getFreeHeap());
  String topic = String("soundspy/") + NODE_ID + "/heartbeat";
  mqtt.publish(topic.c_str(), payload);
}


#define STABILITY_WINDOW_MS 60000  // must stay alive 60s before counting as clean boot

static bool stableBootConfirmed = false;
static unsigned long mqttConnectedAt = 0;

void loop() {
  if (!mqtt.connected()) {
    connectMQTT();
  } else if (!stableBootConfirmed) {
    if (mqttConnectedAt == 0) mqttConnectedAt = millis();
    if (millis() - mqttConnectedAt >= STABILITY_WINDOW_MS) {
      stableBootConfirmed = true;
      crashCounterReset();
      remoteLog("info", "Boot confirmed stable — crash counter reset");
    }
  }
  mqtt.loop();
  sendHeartbeat();


  if (sleeping) {
    delay(100);
    return;
  }

  webSocket.loop();

  size_t bytesRead = 0;
  i2s_read(I2S_PORT, i2s_read_buf, sizeof(i2s_read_buf), &bytesRead, portMAX_DELAY);
  int samplesRead = bytesRead / sizeof(int32_t);

  for (int i = 0; i < samplesRead; i++) {
    int32_t raw = i2s_read_buf[i] >> 8;
    float sample = (float)raw / 8388608.0f;

    // Apply mic gain FIRST - affects everything downstream
    sample *= audioGain;
    sample = constrain(sample, -1.0f, 1.0f);  // Clamp to prevent overflow

    sumSquaresOverall += (double)(sample * sample);

    for (int b = 0; b < NUM_BANDS; b++) {
      float filtered = bands[b].bp1.process(sample);
      filtered = bands[b].bp2.process(filtered);
      bands[b].sumSquares += (double)(filtered * filtered);
    }

    sampleCount++;

    // Convert to 16-bit PCM for streaming (already has gain applied)
    int16_t pcm16 = (int16_t)(sample * 32767.0f);
    audioStreamBuffer[audioStreamIndex++] = pcm16;

    // Send chunk when full (100ms worth)
    if (audioStreamIndex >= STREAM_CHUNK_SIZE) {
      sendAudioChunk();
    }
  }

  // Publish frequency analysis data once per second
  if (millis() - lastPublish >= PUBLISH_INTERVAL_MS && sampleCount > 0) {
    float rmsOverall = sqrt(sumSquaresOverall / sampleCount);
    float dbfsOverall = 20.0f * log10f(rmsOverall + 1e-9f);

    // I2S watchdog: detect sustained silence (bus lockup)
    // Skip during startup grace period
    if (dbfsOverall < I2S_WATCHDOG_DBFS_FLOOR && millis() - bootTime > I2S_STARTUP_GRACE_MS) {
      i2sLockupCount++;
      if (i2sReinitCount >= 3) {
        // Don't reboot — stay alive so MQTT control (OTA, diag) still works
        i2sLockupCount = 0;
        return;
      } else if (i2sLockupCount >= I2S_WATCHDOG_THRESHOLD) {
        reinitI2S();
        i2sLockupCount = 0;
        bootTime = millis();  // fresh grace window after reinit
        sumSquaresOverall = 0;
        sampleCount = 0;
        lastPublish = millis();
        return;
      }
    } else {
      i2sLockupCount = 0;
      i2sReinitCount = 0;  // good data = reset reinit counter
    }

    char payload[512];
    unsigned long timestamp_ms = millis();
    String ipAddress = WiFi.localIP().toString();
    int len = snprintf(payload, sizeof(payload),
      "{\"node\":\"%s\",\"seq\":%u,\"ts\":%lu,\"firmware\":\"%s\",\"ip\":\"%s\",\"overall_dbfs\":%.1f,\"bands\":{",
      NODE_ID, messageSeq++, timestamp_ms, FIRMWARE_VERSION, ipAddress.c_str(), dbfsOverall);

    for (int b = 0; b < NUM_BANDS; b++) {
      float rmsBand = sqrt(bands[b].sumSquares / sampleCount);
      float dbfsBand = 20.0f * log10f(rmsBand + 1e-9f);

      len += snprintf(payload + len, sizeof(payload) - len,
        "\"%s\":%.1f", bands[b].name, dbfsBand);

      if (b < NUM_BANDS - 1) {
        len += snprintf(payload + len, sizeof(payload) - len, ",");
      }

      bands[b].sumSquares = 0;
    }

    len += snprintf(payload + len, sizeof(payload) - len, "}}");

    String topic = String("soundspy/") + NODE_ID + "/data";
    mqtt.publish(topic.c_str(), payload);

    // Don't spam serial with every message (50Hz = too much)
    // Only log important events in other functions

    sumSquaresOverall = 0;
    sampleCount = 0;
    lastPublish = millis();
  }
}

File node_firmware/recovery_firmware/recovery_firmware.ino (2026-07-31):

// soundspy recovery firmware
// Lives in the factory partition — never overwritten by OTA.
// Triggered by: holding BOOT (GPIO0) at reset, or triple-pressing user button (GPIO34) at runtime.
//
// Capabilities:
//   - Reads WiFi + MQTT config from NVS
//   - If credentials missing or WiFi fails: starts AP (soundspy-recovery / soundspy123)
//   - Serves HTTP portal at 192.168.4.1 (AP) or device IP (STA) for:
//     * OTA firmware upload
//     * WiFi + MQTT credential update
//   - Publishes soundspy/<id>/recovery over MQTT when in STA mode

#include <WiFi.h>
#include <WebServer.h>
#include <HTTPUpdateServer.h>
#include <HTTPUpdate.h>
#include <Preferences.h>
#include <esp_ota_ops.h>
#include <PubSubClient.h>
#include <ArduinoJson.h>

#define RECOVERY_VERSION "1.0.0"
#define AP_SSID          "soundspy-recovery"
#define AP_PASS          "soundspy123"
#define PIN_BOOT         0   // built-in BOOT button (active LOW, pull-up)
#define PIN_LED          2   // built-in LED (active HIGH on most NodeMCU boards)

char NODE_ID[13];

Preferences prefs;
WebServer server(80);
HTTPUpdateServer updater;
WiFiClient mqttWifiClient;
PubSubClient mqtt(mqttWifiClient);

bool staMode = false;
String wifiSsid, wifiPass, mqttHost, mqttPort, wsHost, wsPort;

void deriveNodeId() {
  uint64_t mac = ESP.getEfuseMac();
  snprintf(NODE_ID, sizeof(NODE_ID), "%02x%02x%02x%02x%02x%02x",
    (uint8_t)(mac), (uint8_t)(mac >> 8), (uint8_t)(mac >> 16),
    (uint8_t)(mac >> 24), (uint8_t)(mac >> 32), (uint8_t)(mac >> 40));
}

void loadCredentials() {
  prefs.begin("soundspy", true);
  wifiSsid = prefs.getString("wifi_ssid", "");
  wifiPass = prefs.getString("wifi_pass", "");
  mqttHost = prefs.getString("mqtt_host", "");
  mqttPort = prefs.getString("mqtt_port", "1883");
  wsHost   = prefs.getString("ws_host", "");
  wsPort   = prefs.getString("ws_port", "8091");
  prefs.end();
}

void saveCredentials(const String& ssid, const String& pass,
                     const String& mHost, const String& mPort,
                     const String& wHost, const String& wPort) {
  prefs.begin("soundspy", false);
  prefs.putString("wifi_ssid", ssid);
  prefs.putString("wifi_pass", pass);
  prefs.putString("mqtt_host", mHost);
  prefs.putString("mqtt_port", mPort);
  prefs.putString("ws_host",   wHost);
  prefs.putString("ws_port",   wPort);
  prefs.end();
}

bool connectWiFiSTA() {
  if (wifiSsid.isEmpty()) return false;
  WiFi.mode(WIFI_STA);
  WiFi.begin(wifiSsid.c_str(), wifiPass.c_str());
  Serial.print("[recovery] Connecting to WiFi");
  for (int i = 0; i < 20; i++) {
    if (WiFi.status() == WL_CONNECTED) {
      Serial.println(" connected: " + WiFi.localIP().toString());
      return true;
    }
    delay(500);
    Serial.print(".");
  }
  Serial.println(" failed");
  return false;
}

void startAP() {
  WiFi.mode(WIFI_AP);
  WiFi.softAP(AP_SSID, AP_PASS);
  Serial.println("[recovery] AP started: " + String(AP_SSID) + " / " + String(AP_PASS));
  Serial.println("[recovery] Portal: http://192.168.4.1");
}

void blinkLed(int times, int ms = 150) {
  for (int i = 0; i < times; i++) {
    digitalWrite(PIN_LED, HIGH);
    delay(ms);
    digitalWrite(PIN_LED, LOW);
    delay(ms);
  }
}

// --- HTTP portal ---

const char* PORTAL_HTML = R"(<!DOCTYPE html>
<html><head><meta charset='UTF-8'><meta name='viewport' content='width=device-width,initial-scale=1'>
<title>soundspy recovery</title>
<style>
body{font-family:monospace;background:#0a0f0c;color:#8ec9a0;padding:20px;max-width:480px;margin:0 auto}
h1{color:#44dd66;text-shadow:0 0 8px #44dd66}
input{background:#080e0a;border:1px solid #2a4a34;color:#8ec9a0;padding:6px 10px;width:100%;box-sizing:border-box;margin:4px 0 12px;font-family:monospace}
label{color:#4a7a5a;font-size:0.85em}
button{background:#1a3a28;border:1px solid #44dd66;color:#44dd66;padding:8px 20px;cursor:pointer;font-family:monospace;margin-top:8px}
button:hover{background:#2a5a38}
.section{background:#0f1a14;border:1px solid #1a2e24;padding:16px;margin-bottom:16px;border-radius:6px}
h2{font-size:1em;color:#44dd66;margin:0 0 12px}
.info{color:#2a6e3f;font-size:0.8em;margin-bottom:16px}
</style></head>
<body>
<h1>soundspy recovery</h1>
<p class='info'>Node: %NODE_ID% &nbsp;|&nbsp; v%VERSION%</p>
<div class='section'>
  <h2>OTA Firmware Upload</h2>
  <form method='POST' action='/update' enctype='multipart/form-data'>
    <label>Firmware .bin file</label>
    <input type='file' name='firmware' accept='.bin'>
    <button type='submit'>Flash firmware</button>
  </form>
</div>
<div class='section'>
  <h2>Network Configuration</h2>
  <form method='POST' action='/save'>
    <label>WiFi SSID</label><input name='ssid' value='%SSID%'>
    <label>WiFi Password</label><input name='pass' type='password' placeholder='(unchanged if empty)'>
    <label>MQTT Host</label><input name='mqtt_host' value='%MQTT_HOST%'>
    <label>MQTT Port</label><input name='mqtt_port' value='%MQTT_PORT%'>
    <label>WebSocket Host</label><input name='ws_host' value='%WS_HOST%'>
    <label>WebSocket Port</label><input name='ws_port' value='%WS_PORT%'>
    <button type='submit'>Save &amp; Reboot</button>
  </form>
</div>
<div class='section'>
  <h2>Boot Main Firmware</h2>
  <p class='info'>Reboots into the latest valid OTA partition.</p>
  <form method='POST' action='/boot'>
    <button type='submit'>Boot main firmware</button>
  </form>
</div>
</body></html>)";

void handleRoot() {
  String html = String(PORTAL_HTML);
  html.replace("%NODE_ID%", NODE_ID);
  html.replace("%VERSION%", RECOVERY_VERSION);
  html.replace("%SSID%", wifiSsid);
  html.replace("%MQTT_HOST%", mqttHost);
  html.replace("%MQTT_PORT%", mqttPort);
  html.replace("%WS_HOST%", wsHost);
  html.replace("%WS_PORT%", wsPort);
  server.send(200, "text/html", html);
}

void handleSave() {
  String ssid     = server.arg("ssid");
  String pass     = server.arg("pass");
  String mHost    = server.arg("mqtt_host");
  String mPort    = server.arg("mqtt_port");
  String wHost    = server.arg("ws_host");
  String wPort    = server.arg("ws_port");

  if (pass.isEmpty()) pass = wifiPass;  // keep existing if not changed
  saveCredentials(ssid, pass, mHost, mPort, wHost, wPort);

  server.send(200, "text/html",
    "<html><body style='font-family:monospace;background:#0a0f0c;color:#44dd66;padding:20px'>"
    "<h2>Saved. Rebooting...</h2></body></html>");
  delay(1500);
  ESP.restart();
}
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

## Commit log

2026-07-29 Add automated OTA workflow and enhanced dashboard UI
    Features:
    - Automated firmware build/deploy scripts with OTA support
    - Editable alert threshold with slider and text input (-80 to 0 dBFS)
    - Node IP address display alongside firmware version
    - Version history preservation for firmware rollback
    - Arduino CLI initialization script
    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
2026-07-30 v1.0.0: I2S watchdog, credential cleanup, UI modals
    Add automatic I2S bus recovery (reinit after 5 dead reads, reboot as
    fallback). Remove hardcoded credentials from firmware source — all
    config now injected from .env at build time. Consolidate firmware into
    single node_firmware.ino. Replace browser confirm() with in-UI modal.
    Remove threshold input spinner arrows.
    [node_firmware.ino]
2026-07-30 Fixing watchdog grace time for boot
    [node_firmware.ino]
2026-07-30 Added cad files for PCB with breakout mount for mic
    [soundspy-mic-breakout.kicad_pcb, soundspy-mic-breakout.kicad_sch]
2026-07-30 v1.1.0: Hardcode firmware config, simplify build to version-only injection
    Firmware no longer depends on .env for network config — WiFi SSID, MQTT/WS
    hosts and ports are hardcoded in the .ino source. Build script only injects
    FIRMWARE_VERSION and WIFI_PASSWORD (secrets stay in gitignored .env).
    [node_firmware.ino]
2026-07-30 v1.2.1: Remote logging, OTA rollback, dashboard live logs, UI polish
    - Firmware: remote logging over MQTT (soundspy/<node>/log and /boot topics),
    OTA rollback via esp_ota_mark_app_valid_cancel_rollback(), deep sleep command
    - Build: all config injected from .env via placeholders, version stays in .ino,
    rendered .ino generated for Arduino IDE manual flashing
    - Dashboard: live logs panel with per-node sidebar and app/system tabs,
    threshold-relative chart zones, canvas-drawn Y-axis on spectrum,
    sleep button, standardized spacing
    - Cleanup: removed stale test-deployment.sh, fixed deploy_ota.sh host resolution
    [node_firmware.ino]
2026-07-30 Dashboard UI: per-node history selector, level meter bar, threshold slider improvements
    - History chart filters datasets by selected node with per-node zone backgrounds
    - Vertical level meter bar with segmented blocks, peak hold, and zone colors
    - Threshold slider: tick marks every 10dB, snap-to-mark, dynamic zone indicators
    - Slider thumb changed to neutral color, step=0.5, double-click resets to -20
    - Button icons: half-moon for sleep, plain arrow for update
2026-07-30 Dashboard UI: oscilloscope level display, meter bar, slider marks, knob fixes
    - Overall level display restyled as CRT oscilloscope (phosphor green, vignette)
    - Level meter bar added beside display with segmented blocks and peak hold
    - Threshold slider: tick marks every 10dB with snap, zone indicators, neutral thumb
    - Knob indicator aligned to center, faster drag sensitivity
    - Alert border uses smoothed level with strict > threshold
    - Button icons: half-moon sleep, arrow update
    - EMA alpha increased for more responsive level display
2026-07-30 v1.3.0: Generic firmware with chip ID node identity, dashboard node naming
    Node ID is no longer configured at build time. Firmware derives a 6-char
    hex ID from the ESP32's EfuseMAC at runtime, making the binary generic —
    compile once, flash to any board.
    Dashboard persists chip_id → display_name mapping in data/node_names.json,
    auto-assigns "node-N" for new nodes, and supports rename via double-click.
    - Firmware: removed PLACEHOLDER_NODE_ID, added char NODE_ID[7] from getEfuseMac()
    - Build script: no longer takes NODE_ID arg, outputs generic soundspy_v<ver>.bin
    - Deploy script: takes chip_id (visible in dashboard) as argument
    - Dashboard: added node name persistence, /api/node/rename e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
    [node_firmware.ino]
2026-07-30 Dashboard UI polish: header font, inline rename, icon consistency
    - Header: Share Tech Mono font with phosphor green glow, compact height
    - Node rename: inline contenteditable (no browser prompt)
    - Edit button (✎) next to node name, audio indicator moved next to mute btn
    - Mute/unmute uses ◁ speaker icon, no emojis
    - Online status dot has green glow
    - Knob sensitivity increased
2026-07-30 v1.3.1: Fix duplicate chip IDs, green color palette
    - Chip ID now uses lower 4 bytes of EfuseMAC (8-char hex) instead of
    middle 3 bytes which could collide across boards from same batch
    - Dashboard color palette shifted from blue/purple to green throughout
    (backgrounds, borders, accents, knob ticks) matching hardware EQ aesthetic
    [node_firmware.ino]
2026-07-30 v1.4.0: Sleep/wake, heartbeats, dBFS/dBA toggle, history power-domain averaging
    - Soft sleep mode: I2S stops, MQTT stays alive, node wakeable from dashboard
    - 30s heartbeat from firmware; backend uses it to distinguish sleeping vs crashed
    - dBFS/dBA toggle on level display (click unit label); applies to meter, EQ, history
    - History now averages in linear power domain — fixes compressed dynamic range
    - Firmware version updates live via socket
    - Sleeping nodes show "Sleeping" not "Offline"; state persists across reloads
    - Chart/separator lines brighter; threshold spacing increased; avg legend toggle fixed
    [node_firmware.ino]
2026-07-30 v1.4.1: dBA default, fixed threshold line, raw level meter bar
    - dBA is now the default display mode on load
    - All UI elements (threshold unit, chart Y-axis, avg label) toggle together
    - Threshold stored as dBFS internally; A-weighting offset cached on first band
    data arrival instead of recomputed per frame — fixes drifting threshold line
    - Level meter bar follows raw unsmoothed signal; number stays EMA-smoothed
    - Zone backgrounds and alert comparisons consistent with active display unit
2026-07-30 Codebase cleanup: remove dead code, fix PCB file, update .env.example
    dashboard.py:
    - Remove unused imports: datetime, base64, os_module alias
    - Remove SSE /stream route (superseded by Socket.IO)
    - Remove handle_audio_stream SocketIO handler (never called)
    dashboard.html:
    - Remove getEffectiveThreshold() (never called)
    - Remove realtimeStartTs (never read)
    - Remove hidden spectrum-container HTML block (replaced by canvas EQ)
    - Remove permanently-hidden knob-value elements
    - Remove orphaned CSS: .reading*, .threshold-info, .threshold-value
    node_firmware.ino:
    - Remove unused #include <HTTPClient.h>
    - Remove unused #define STREAM_SAMPLE_RATE
    .env.example:
    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
    [soundspy-mic-breakout.kicad_pcb]
2026-07-30 v1.4.2: UI polish — controls, colors, threshold dBA default
    - Level bar moved left of number display; darker bg + green border
    - Spectrum: 8px right padding to match top/bottom margins
    - Control boxes (knobs, threshold): dark bg + border, instrument panel feel
    - Labels: #6b9e7a muted green; accents: #a3e6b8 mint
    - Threshold defaults to -20 dBA; calibrates to dBFS on first band data;
    toggling dBFS<->dBA no longer drifts the value
    - Level number: fixed 3ch min-width so minus sign doesn't shift centering
    - Status online/sleeping pill: boxed non-interactive style
    - Speaker SVG for mute button; fixed width so it doesn't resize on toggle
    - Live logs: +/- toggle icon on left
    - Level meter zone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
2026-07-30 Security: upgrade deps to fix Dependabot alerts; add favicon
    requirements.txt:
    - python-socketio 5.11.1 -> 5.16.3 (fixes high DoS + medium RCE alerts)
    - flask-socketio 5.3.6 -> 5.6.1
    - flask 3.0.0 -> 3.1.3 (fixes low Vary: Cookie alert)
    - requests 2.31.0 -> 2.33.0 (fixes 3 medium alerts)
    - simple-websocket 1.0.0 -> 1.1.0
    - SVG favicon: 5-bar EQ icon in phosphor green on dark background
    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
2026-07-30 v1.4.3: Button borders, filter labels, node name flash fix
    - Buttons: subtle #2a4a34 border at rest, #44dd66 on hover
    - History selectors: same border treatment
    - Filter labels: larger (0.8em), green (#6b9e7a), spaced from selectors
    - Pre-populate nodeDisplayNames on page load to prevent ID→name flash
2026-07-30 v1.4.4: Level centering, threshold layout, collapsible history, green palette
    - Level digits centered under label; minus sign absolutely positioned left
    - Threshold input centered with hidden spacer balancing unit label
    - Level History collapsible with +/- toggle, starts expanded
    - Button/selector text #6b9e7a (muted green, was blue-grey)
    - Offline dot and audio indicator dark green instead of grey
2026-07-30 v1.4.5: Knob display labels, button colors, threshold label styling
    - Knob values: dark bg, border, monospace, larger font
    - Knob labels: dark display background with border
    - Alert Threshold label: 10px 20px padding, display bg
    - Button/selector text: #8ec9a0 (brighter green)
    - Log Clear button: matches action button border + hover style
2026-07-30 v1.4.6: HiDPI spectrum, hot-reload, color polish, band label alignment
    - Canvas renders at devicePixelRatio — fixes blurry text on retina screens
    - watchdog hot-reload added (no container restart needed for template changes)
    - Dashboard version in footer from DASHBOARD_VERSION constant
    - Spectrum: 160px tall, 30px Y-axis, band labels on 6-column grid
    - Y-axis/band/slider colors lifted to #9ecfb0
    - Buttons: phosphor green rgba(68,221,102,0.9)
    - Online pill, node info, chart axis labels all shifted to green palette
    - eq-container border + dark bg matching control boxes
    - Filter labels bold + brighter
2026-07-30 v1.4.7: Alert LED, LED-style indicators, band label alignment
    - Red alert LED box next to threshold; triggers on raw level for instant response
    - Card border no longer flashes on alert — LED is sole indicator
    - Audio indicator + online dot: LED style (radial gradient, glow, recessed dome)
    - Blink animation dims to 35% for visible pulse
    - Status pill gap 8px; audio indicator restored outside button
    - Spectrum 160px tall, 30px Y-axis; band labels on 6-column grid
    - eq-container border + dark bg
2026-07-30 Switch license to AGPL-3.0
2026-07-30 Add wiki documentation files
    Architecture, Hardware Wiring, Firmware Setup, Dashboard, Troubleshooting, Adding Nodes
2026-07-30 Remove wiki/ folder — docs live in the GitHub wiki repo
2026-07-30 PCB: node carrier board + fix breakout layout
    soundspy-node.kicad_pcb:
    - ESP32 38-pin DevKit carrier (30x68mm)
    - ICS-43434 on standoff pins, sound port hole at top
    - USB-C notch at bottom edge for case passthrough
    - 4x M2 mounting holes
    - 100nF decoupling cap, GND fill on B.Cu
    - I2S traces (SCK/WS/SD) routed non-crossing
    soundspy-mic-breakout.kicad_pcb (v1.1):
    - Fix: J1 was off-board (pads at y=16mm on 12mm board)
    - Center J1 vertically, all pads within bounds
    - Fix crossing traces, correct pad-to-net assignments
    - Use standard KiCad footprint libraries
    Preview PNGs added for both boards
    [soundspy-mic-breakout.kicad_pcb, soundspy-node.kicad_pcb]
2026-07-30 Remove breakout board files, superseded by node carrier board
    [soundspy-mic-breakout.kicad_pcb, soundspy-mic-breakout.kicad_sch]
2026-07-30 Release workflow: attach PCB files as zip asset
2026-07-30 Workflow: include all files from pcb/ in release zip
2026-07-30 Add KiCad project and schematic files for node carrier board
    [soundspy-node.kicad_sch]
2026-07-30 Fix PCB and schematic files: remove invalid ;; comments, simplify schematic to valid KiCad syntax
    [soundspy-node.kicad_pcb, soundspy-node.kicad_sch]
2026-07-30 PCB: fix mic connector to correct 2x3 2.54mm footprint, remove all traces
    - Replace wrong 1x5 1.27mm header with correct 2x3 2.54mm layout
    - Pin layout: GND/VDD/SD (top row), LR/WS/SCK (bottom row)
    - Row separation 7.62mm, column pitch 2.54mm (from barafael/inmp441-breakout-kicad)
    - Pad drill 0.762mm, pad size 1.524mm
    - Sound port hole corrected to 3mm
    - Added I2S_LR net (L/R select pin, ties to GND for left channel)
    - Removed all crossing traces — ready for routing in KiCad
    [soundspy-node.kicad_pcb]
2026-07-30 Add pcb/mics/inmp441/DESIGN.md with module specs and carrier board reference
2026-07-30 Restructure pcb/: move all files to pcb/inmp441/, remove mics/ subfolder
    [soundspy-node.kicad_pcb, soundspy-node.kicad_sch]
2026-07-30 PCB v1.2: correct 2x3 mic footprint, non-crossing traces
    - J_MIC moved to (15,10) with correct 6-pad 2x3 layout
    - Pad drill 0.762mm, size 1.524mm (from verified INMP441 footprint data)
    - Sound port hole 3mm at mic connector center
    - 3V3/GND/SCK/WS routed on F.Cu without crossings
    - SD routed on B.Cu via vias to avoid crossing other signals
    - ESP32 headers at y=16 for clearance above mic area
    - Removed stale pcb/DESIGN.md (content moved to pcb/inmp441/DESIGN.md)
2026-07-30 PCB v1.2: routed traces, correct 2x3 mic footprint, no crossings
    - 3V3/GND/SCK/WS on F.Cu, SD on B.Cu via vias (no crossings)
    - Correct INMP441 footprint: 2x3, drill 0.762mm, pad 1.524mm
    - Sound port hole 3mm, J_MIC at y=10 for board clearance
    [soundspy-node.kicad_pcb]
2026-07-30 Add PCB release workflow: auto-publish zip on pcb/ changes
2026-07-30 PCB versioning: per-model VERSION file, release on VERSION change
    - pcb/inmp441/VERSION: 1.2
    - Workflow detects which model's VERSION changed, builds only that zip
    - Releases as pcb-<model>-v<version> tag and GitHub release
    - Skips if tag already exists
2026-07-30 PCB inmp441: bump to v1.3
2026-07-30 Update CLAUDE.md with PCB design context
2026-07-31 Persist per-node thresholds, realtime offline detection, red LED
    - Thresholds saved to node_thresholds.json, restored on reload
    - Removed dBA/dBFS recalculation on thresholds (store as-set)
    - Client-side staleness check dims nodes within seconds of disconnect
    - Offline status LED is now static red with glow
2026-07-31 v1.5.0: full 6-byte node ID, UI fixes, log persistence
    - Fix duplicate node IDs: use all 6 MAC bytes (was lower 4 only)
    - Persist per-node thresholds across reloads (node_thresholds.json)
    - Remove threshold dBFS/dBA recalculation — store exactly as set
    - Realtime offline detection via browser-clock staleness check
    - Fix node card flashing: clock skew between server/browser timestamps
    - Reduce DOM thrashing: guard writes, RAF batching, throttle app log
    - Fix canvas flash: round DPR dimensions to prevent every-frame reset
    - System logs persist across reload (server keeps last 200, replays on connect)
    - Node name shown alongside ID in log entries
    - Distinct node colors for history chart (blue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
    [node_firmware.ino]
2026-07-31 release: remove PCB packaging from core release workflow
2026-07-31 v1.6.0: EQ peak markers, Peaks/Hold toggles, UI polish
    - Peak markers always visible on EQ bars, fade after 2s
    - Peak Hold toggle keeps markers indefinitely
    - Peaks toggle to hide markers entirely; disabling peaks auto-disables hold
    - Enabling hold auto-enables peaks
    - Node colors use blues/purples/pinks (avoids green/yellow/red zone colors)
    [node_firmware.ino]
2026-07-31 v2: Phase 0-1 complete — modular refactor, SQLite, cleanup
    - Delete threshold_monitor.py and its Dockerfile
    - Remove monitor and ntfy services from docker-compose
    - Extract helpers.py: dBFS math, A-weighting, band constants
    - Extract db.py: SQLite schema, migration from JSON, all DB access
    - Extract node_state.py: in-memory node data, history, heartbeat
    - Extract notifications.py: alert engine skeleton, channel dispatchers
    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
2026-07-31 v2: Phase 5 — settings UI (channels, rules, alert history)
2026-07-31 fix: restore audio WebSocket relay (ESP32 sends JSON+b64, not raw bytes)
2026-07-31 hw_experiments: factory recovery partition system
    - New partitions.csv: factory (512KB, OTA-immune) + ota_0/ota_1 (1.5MB each)
    - recovery_firmware/: minimal HTTP portal for OTA upload + credential config
    - AP fallback (soundspy-recovery) if WiFi credentials missing/fail
    - Publishes soundspy/<id>/recovery over MQTT when in STA mode
    - Web UI: OTA upload, WiFi/MQTT config, boot main firmware button
    - Main firmware: credentials moved from PLACEHOLDER_ compile-time injection
    to NVS (Preferences), read at runtime; PLACEHOLDER_ values remain as fallback
    - Crash counter in RTC: after 3 consecutive boot failures, boots into recovery
    - BOOT button (GPIO0) held at startup → recovery immediate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
    [partitions.csv]
2026-07-31 hw_experiments: NVS crash counter, MQTT OTA in recovery, debounce fix
    - Crash counter moved from RTC to NVS — survives hard resets and power loss
    - Replace ESP.restart() with esp_restart() throughout to preserve RTC memory
    - Button debounce increased to 500ms to reduce false triggers
    - Recovery firmware: MQTT subscribe to control topic, handles ota_url command
    - Updated partition layout: factory 1MB, ota_0/ota_1 1.4MB each
    - partitions.csv copied to node_firmware/ for Arduino IDE custom scheme
    [partitions.csv]
2026-07-31 v1.7.4: remove button/pot code, add recovery mode indicator in dashboard
2026-07-31 v1.7.5: remove BOOT button recovery logic (GPIO0 not usable at runtime)
2026-07-31 Cleanup: remove stale files (dashboard.py, duplicate partitions.csv, ntfy placeholders, V2_PLAN)
    [partitions.csv]
2026-07-31 v1.7.7: heartbeat prints to serial+dashboard log, 10s interval
2026-07-31 serial_monitor: default to all ttyUSB devices when no args given
2026-07-31 serial_monitor: use cat instead of tail -f for serial devices
2026-07-31 fix: clear log button works in fullscreen mode
2026-07-31 fix: attach logContentFs scroll listener after element exists in DOM
2026-07-31 settings: bump font sizes (13px base → 15px, scale all em values up)
